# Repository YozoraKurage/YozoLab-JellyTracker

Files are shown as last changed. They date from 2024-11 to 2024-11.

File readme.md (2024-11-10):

# Yozolab-JellyTracker

### ✨️現在作成中です！✨️

私の作った[SlimeVR](https://github.com/SlimeVR)トラッカーに関するリポジトリです。

## FW書き込みについて(書き途中です)
JellyTrackerを私から購入した場合、WebページからFWの更新ができます \
https://jt-webflash.yozolab.net/

## 動作確認済みデータ
- [x] JellyTracker_V0.2.0
- [x] JellyTracker_V0.5.0
- [x] LSM_Module_V0.1.0
- [x] Ni-MH_3.3V-Module_V0.1.0

## KiCADデータについて
(今のところ)すべてKiCAD 7.0で作成されています\
私の導入しているプラグイン
- Espressif Library
- KiCAD JLCPCB tools

## JT_V0.5.0
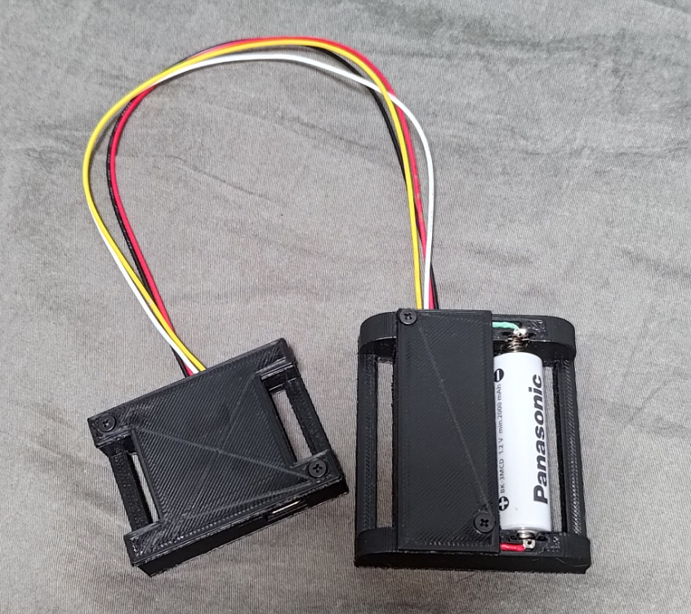
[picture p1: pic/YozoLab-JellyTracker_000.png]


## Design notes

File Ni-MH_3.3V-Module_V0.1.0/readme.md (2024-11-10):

# NiMH 3.3V昇圧モジュール
Ni-MHを3.3Vへ昇圧するモジュールです。

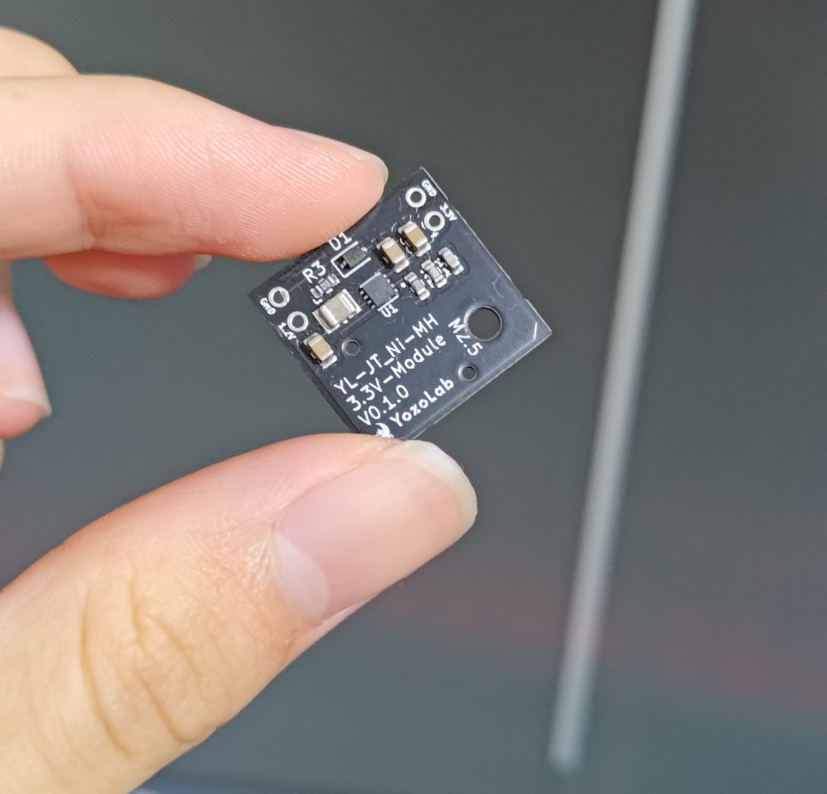
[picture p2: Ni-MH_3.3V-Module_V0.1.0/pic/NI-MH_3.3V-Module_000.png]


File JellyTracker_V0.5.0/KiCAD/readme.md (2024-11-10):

# JellyTracker_V0.5.0 KiCADデータ

> [!NOTE]
> このKiCADデータはKiCAD V7.0で作成されました！

AUXトラッカーとして、LSM_Module-V0.1.0が利用可能です
> LSM_ModuleとNi-MH_3.3V-Moduleを利用してNi-MH一本での運用が可能です。\
> JT_V0.5.0はそのために作成されました

## How to Upload to JLCPCB
jlcpcb/production_filesに出力されたBOM、CPL、GERBERデータがあるので、それを使うかKiCADからデータを作成してください

## Parts list

| What's it? | Parts Name | LCSC No. |
| ---- | ---- | ---- |
| TypeC Connector | TYPE-C-31-M-12 | C165948 |
| ESP32C3 Module | ESP32-C3-WROOM-02-N4 | C2934560 |
| 3.3V Regulator | ME6211C33M5G-N | C82942 |
| PushButton | SKRKAEE020 | C115357 |
| Caps | CL21B105KBFNNNE | C28323 |
| Resistor | 0603WAF5101T5E  | C23186 |
| Resistor | 0603WAF1002T5E  | C25804 |
| Diode | CUS10S30,H3F | C146335 |
| PH 2.0 | PH-4P | C50137 |

> [!IMPORTANT]
> 私のPH2.0ケーブルでは、必ず **SameSide** のケーブルを使う必要があります！

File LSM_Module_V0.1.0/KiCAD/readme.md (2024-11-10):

# LSM_Module_V0.1.0 KiCADデータ

LSM6シリーズ、及びBMIシリーズのモジュールにコネクタを付けてAUXトラッカーとして扱うための基板データです。

白猫屋さんのこのLSM6DSVモジュールでの動作を確認済みです。\
https://booth.pm/ja/items/5606882

## How to Upload to JLCPCB
jlcpcb/production_filesに出力されたBOM、CPL、GERBERデータがあるので、それを使うかKiCADからデータを作成してください

## Parts list
| Parts Name | LCSC No. |
| ---- | ---- |
| PH2.0mm 4pin | C50137 or https://www.aliexpress.com/item/1005006027334406.html |
| PH2.0mm 4pin-wire **SameSide** | https://ja.aliexpress.com/item/1005003395992629.html |

> [!IMPORTANT]
> 私のPH2.0ケーブルでは、必ず **SameSide** のケーブルを使う必要があります！

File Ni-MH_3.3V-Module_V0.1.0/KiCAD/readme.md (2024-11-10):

# NiMH 3.3V昇圧モジュール KiCADデータ
Ni-MHを3.3Vへ昇圧するモジュールです。

## How to Upload to JLCPCB
jlcpcb/production_filesに出力されたBOM、CPL、GERBERデータがあるので、それを使うかKiCADからデータを作成してください

## Parts list
| What's it? | Parts Name | LCSC No. |
| ---- | ---- | ---- |
| Caps | CL10C100JB8NNNC | C1634 |
| Inductor | DFE252012P-R47M=P2 | C237552 |
| Resistor | 0603WAF3163T5E | C25814 |
| 1.2v to 3.3v DCDC | TPS61021ADSGR | C193037 |
| Caps | CL21A226MAQNNNE  | C45783 |
| Resistor | 0603WAF1003T5E | C25803 |
| Diode | CUS10S30,H3F | C146335 |

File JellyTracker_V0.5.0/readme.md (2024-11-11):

# JellyTracker_V0.5.0

JT_V0.5.0は動作確認済みです！

この基板では、ESP32-C3-WROOM-02-N4とLSM6DSVのモジュールを利用して作るトラッカーです。

白猫屋さんのこのLSM6DSVモジュールでの動作を確認済みです。\
https://booth.pm/ja/items/5606882

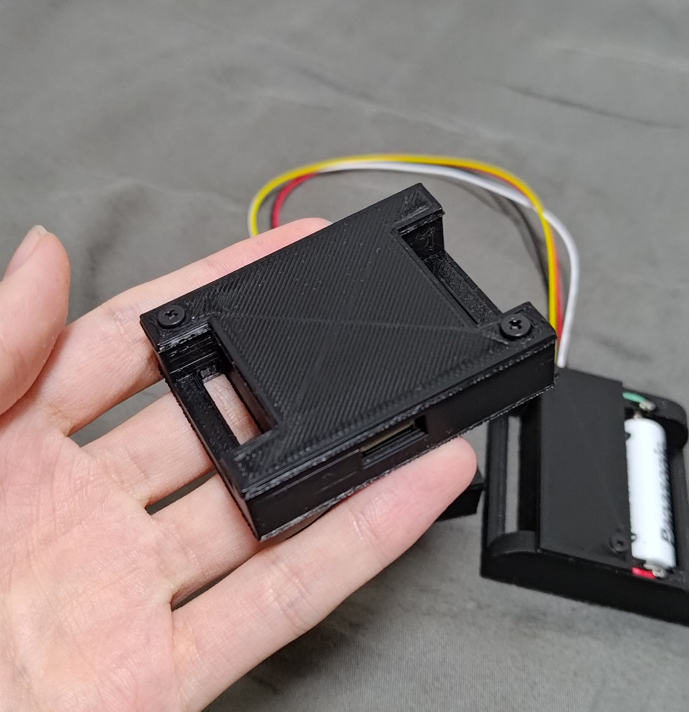
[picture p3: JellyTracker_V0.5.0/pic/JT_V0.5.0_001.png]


# JellyTracker_V0.5.0 FW

JT_V0.5.0で書き込み可能なカスタム済みFW一覧です。

> [!NOTE]
> FWデータは[JellyTracker-FW](https://github.com/YozoraKurage/JellyTracker-FW)リポジトリに移動しました！

| Branch Name | Repository |  |
| ---- | ---- | ---- |
| sfusion-tuned-mbe_V0.5.0 | https://github.com/YozoraKurage/JellyTracker-FW/tree/sfusion-tuned-mbe_V0.5.0 | 安定版 |
| dynamic-sfusion_V0.5.0 | https://github.com/YozoraKurage/JellyTracker-FW/tree/dynamic-sfusion_V0.5.0 | 実験的 |

## How to Flash FW
JT-V0.5.0であれば、[YozoraLaboratory ESPTool](https://jt-webflash.yozolab.net/)からWeb上でのFW書き込みが可能です。\
カスタマイズしたい場合はそれぞれFWをダウンロードしてお使いください。

## Topics

JT-V0.5.0のFWはすべて、Ni-MH1本での運用に対応するために
- 電源投入時にDeepSleepへ入る処理(RFキャリブレーションのスキップ)
- WiFiの出力強度の変更(2dbm)
- CPUクロック数の変更(80MHz)

が行われています。\
これらは主に省電力化、電源投入時の突入電流対策です。

また、sfusion-tuned-mbeではCPUクロックが80MHzで耐えられなかったため、180Mhzへと変更されています。

## 各FWについて

### sfusion-tuned-mbe_V0.5.0では
FWを書き込んだ初回にのみ6面キャリブレーションが必要です。\
詳しくは[公式ドキュメント](https://docs.slimevr.dev/server/imu-calibration.html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)を御覧ください。\
(このFWは起動時にDeepSleepへと突入するため、シリアルコンソールが一時的に外され、6面キャリブレーションが少しやりにくくなっています！ごめんなさい;;)

### dynamic-sfusion_V0.5.0では
これは6面キャリブレーションが必要ないFWです。\
現在実験中！\
~~例として、[PandaTrackers](https://github.com/purraricat/SlimeVR-CheeseCake-PandaTrackers/blob/main/docs/LSM6DSV-tips.md)ではMBEは非推奨と書かれています。(2024/11/10時点)~~\
彼はSlimeVR Discordコミュニティから正当な理由によってBANされているようでした...

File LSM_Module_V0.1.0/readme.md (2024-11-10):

# LSM_Module_V0.1.0
LSM6シリーズ、及びBMIシリーズのモジュールにコネクタを付けてAUXトラッカーとして扱うための基板データです。

白猫屋さんのこのLSM6DSVモジュールでの動作を確認済みです。\
https://booth.pm/ja/items/5606882

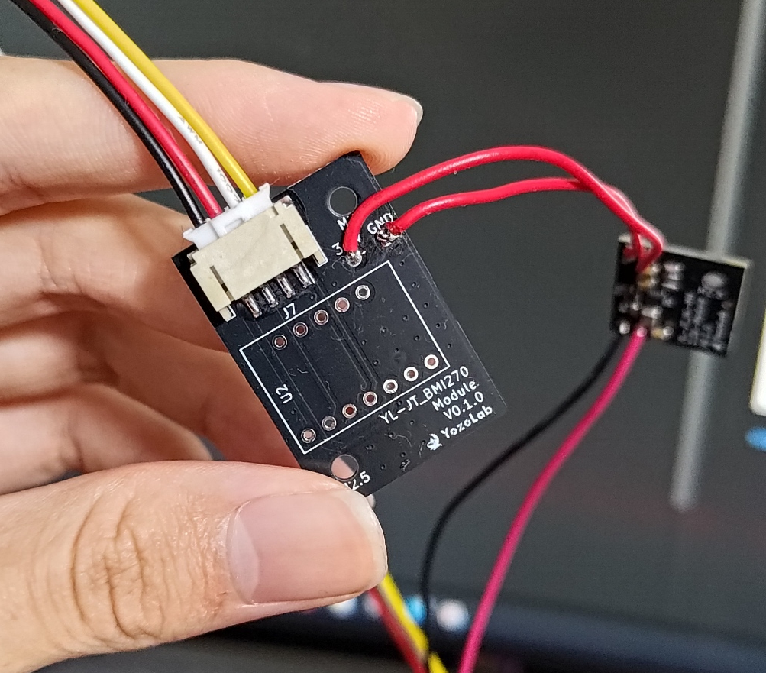
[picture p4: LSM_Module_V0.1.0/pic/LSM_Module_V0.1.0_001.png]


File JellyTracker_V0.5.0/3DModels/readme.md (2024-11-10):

# JellyTracker_V0.5.0 3DModels
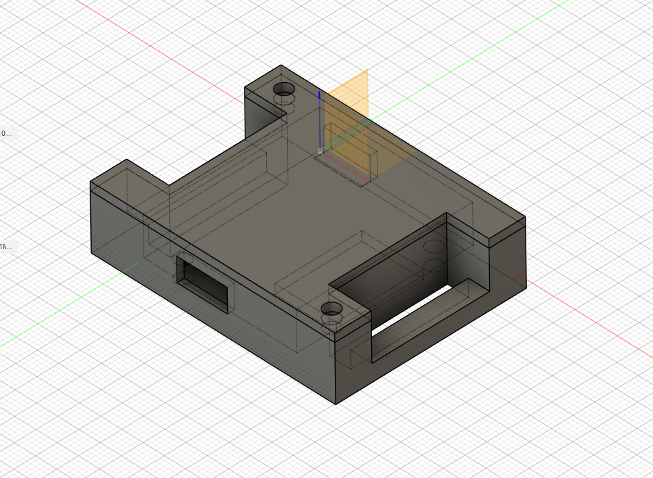
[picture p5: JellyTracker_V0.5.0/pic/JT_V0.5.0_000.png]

ネジは2.5M、穴が空いているところに2.5M、幅3.5mmインサートナットをねじ込む感じです

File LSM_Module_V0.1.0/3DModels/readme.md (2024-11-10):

# JellyTracker_V0.5.0 3DModels
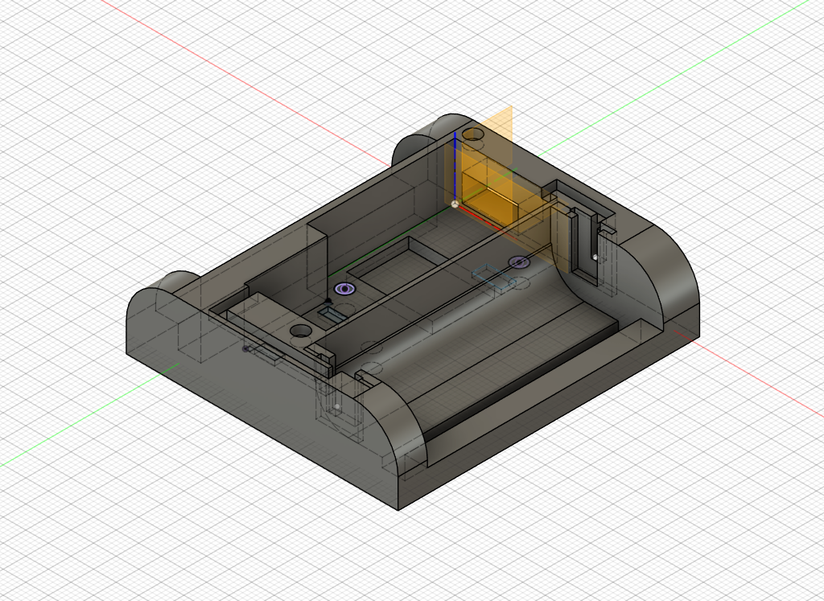
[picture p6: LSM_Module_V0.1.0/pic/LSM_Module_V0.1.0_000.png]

ネジは2.5M、穴が空いているところに2.5M、幅3.5mmインサートナットをねじ込む感じです

単3電池端子は[これ](https://www.amazon.co.jp/dp/B0C57XDT56?ref=ppx_yo2ov_dt_b_fed_asin_title&th=1)

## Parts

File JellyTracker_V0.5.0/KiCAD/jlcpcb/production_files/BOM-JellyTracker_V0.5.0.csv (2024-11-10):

Comment | Designator | Footprint | LCSC | Quantity
SW_Push | SW1,SW2 | SW_Push_SPST_NO_Alps_SKRK | C115357 | 2
CUS10S30 | D2 | D_SOD-323 | C146335 | 1
USB_C_Receptacle_USB2.0 | J1 | USB_C_Receptacle_HRO_TYPE-C-31-M-12 | C165948 | 1
5.1k | R1,R2 | R_0603_1608Metric | C23186 | 2
10k | R3,R4 | R_0603_1608Metric | C25804 | 2
1μF | C6,C7 | C_0805_2012Metric | C28323 | 2
ESP32-C3-WROOM-02 | U5 | ESP32-C3-WROOM-02 | C2934560 | 1
JST-PH 2.0 | J7 | JST_PH_S4B-PH-SM4-TB_1x04-1MP_P2.00mm_Horizontal | C50137 | 1
ME6211C33M5G-N | U1 | SOT-23-5 | C82942 | 1

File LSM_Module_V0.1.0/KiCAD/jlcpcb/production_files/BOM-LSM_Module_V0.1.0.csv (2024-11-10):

Comment | Designator | Footprint | LCSC | Quantity
JST-PH 2.0 | J7 | JST_PH_S4B-PH-SM4-TB_1x04-1MP_P2.00mm_Horizontal | C50137 | 1

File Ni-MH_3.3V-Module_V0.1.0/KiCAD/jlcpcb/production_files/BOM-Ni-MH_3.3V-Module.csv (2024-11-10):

Comment | Designator | Footprint | LCSC | Quantity
CUS10S30 | D1 | D_SOD-323 | C146335 | 1
10pF | C2 | C_0603_1608Metric | C1634 | 1
TPS61021ADSGR | U1 | SON50P200X200X80-9N | C193037 | 1
DFE252012P-R47M=P2 | L1 | INDC2520X120N | C237552 | 1
100k | R2,R3 | R_0603_1608Metric | C25803 | 2
316k | R1 | R_0603_1608Metric | C25814 | 1
22uF | C1,C3,C4 | C_0805_2012Metric | C45783 | 3

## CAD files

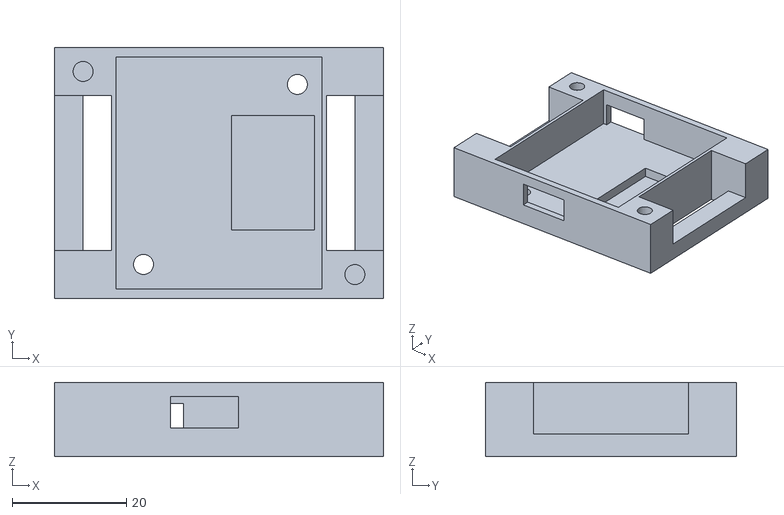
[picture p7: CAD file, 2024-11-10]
JellyTracker_V0.5.0/3DModels/JT-V0.5.0_Bottom.stl
57.6 x 43.9 x 13.0

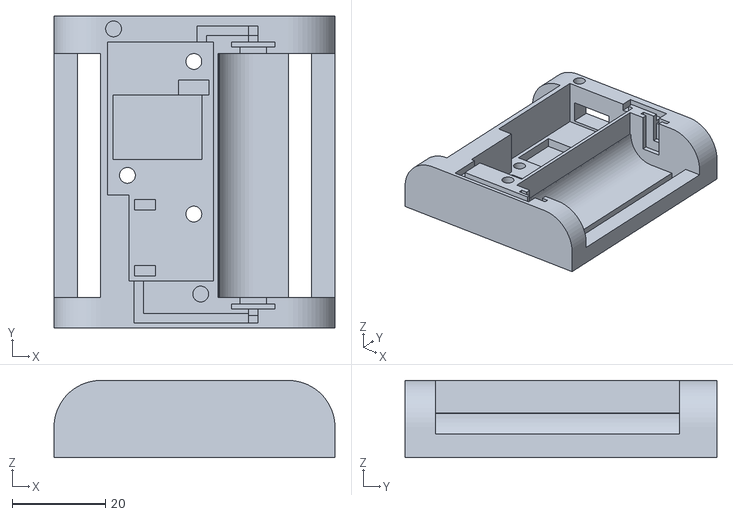
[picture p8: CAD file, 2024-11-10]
LSM_Module_V0.1.0/3DModels/LSMModule_V0.1.0_Bottom.stl
60.2 x 66.7 x 16.5

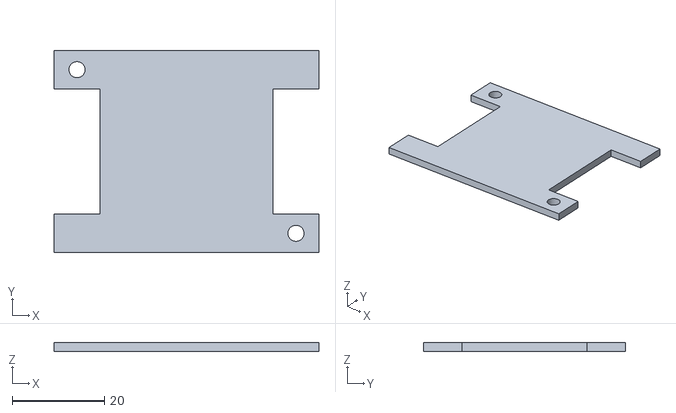
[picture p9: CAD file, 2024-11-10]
JellyTracker_V0.5.0/3DModels/JT-V0.5.0_Top.stl
57.6 x 43.9 x 2.00

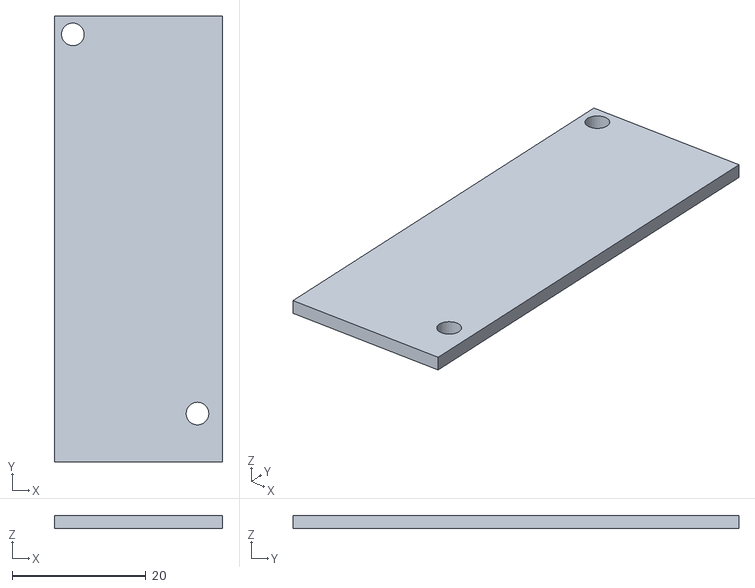
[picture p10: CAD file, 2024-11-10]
LSM_Module_V0.1.0/3DModels/LSMModule_V0.1.0-Top.stl
25.2 x 66.7 x 2.00

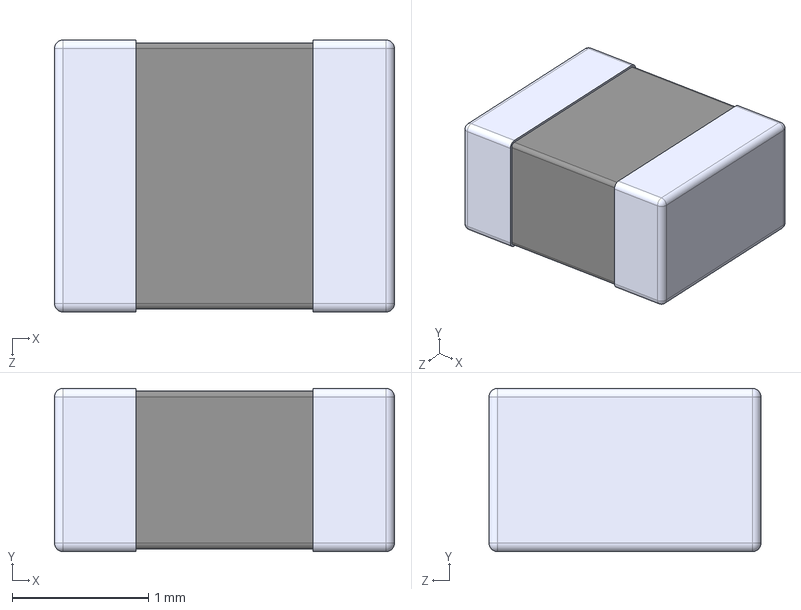
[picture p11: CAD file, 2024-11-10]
JellyTracker_V0.5.0/KiCAD/other.footprints/DFE252012P-R47M_P2/DFE252012P-R47M_P2.step
2.50 x 1.20 x 2.00 mm

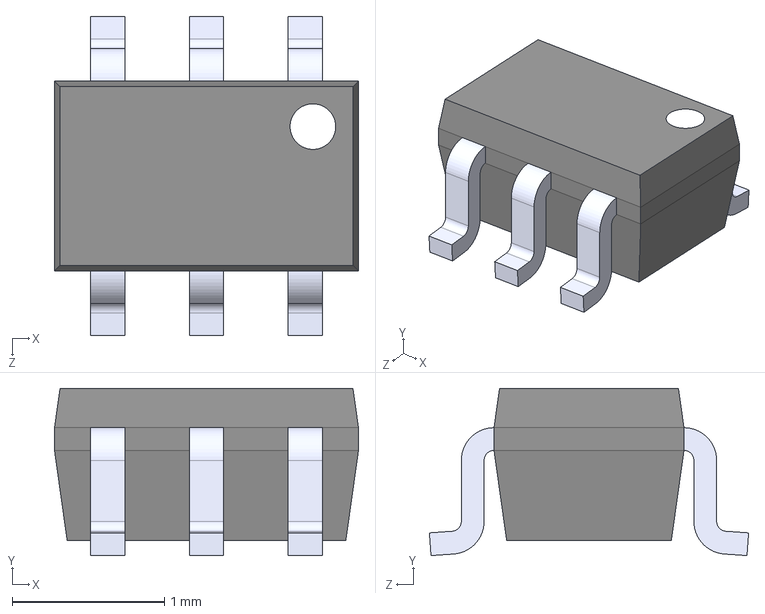
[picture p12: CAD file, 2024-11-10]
JellyTracker_V0.5.0/KiCAD/other.footprints/LM66100DCKR/LM66100DCKR.step
2.00 x 1.10 x 2.10 mm

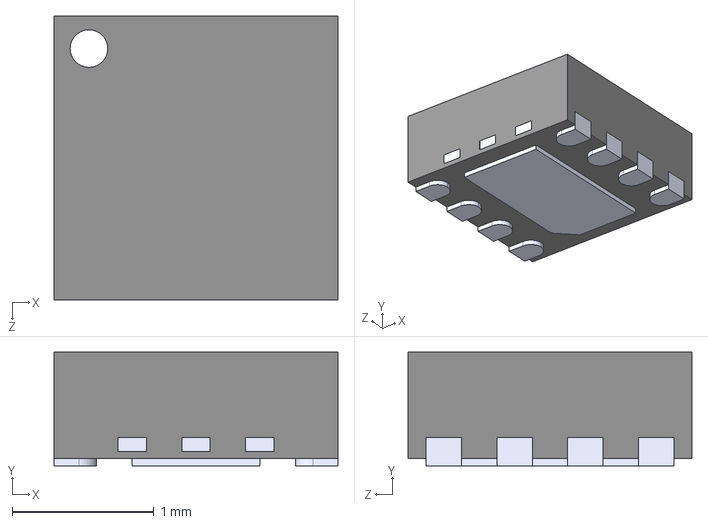
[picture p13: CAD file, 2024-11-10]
JellyTracker_V0.5.0/KiCAD/other.footprints/TPS61021ADSGR/TPS61021ADSGR.step
2.00 x 0.8 x 2.00 mm

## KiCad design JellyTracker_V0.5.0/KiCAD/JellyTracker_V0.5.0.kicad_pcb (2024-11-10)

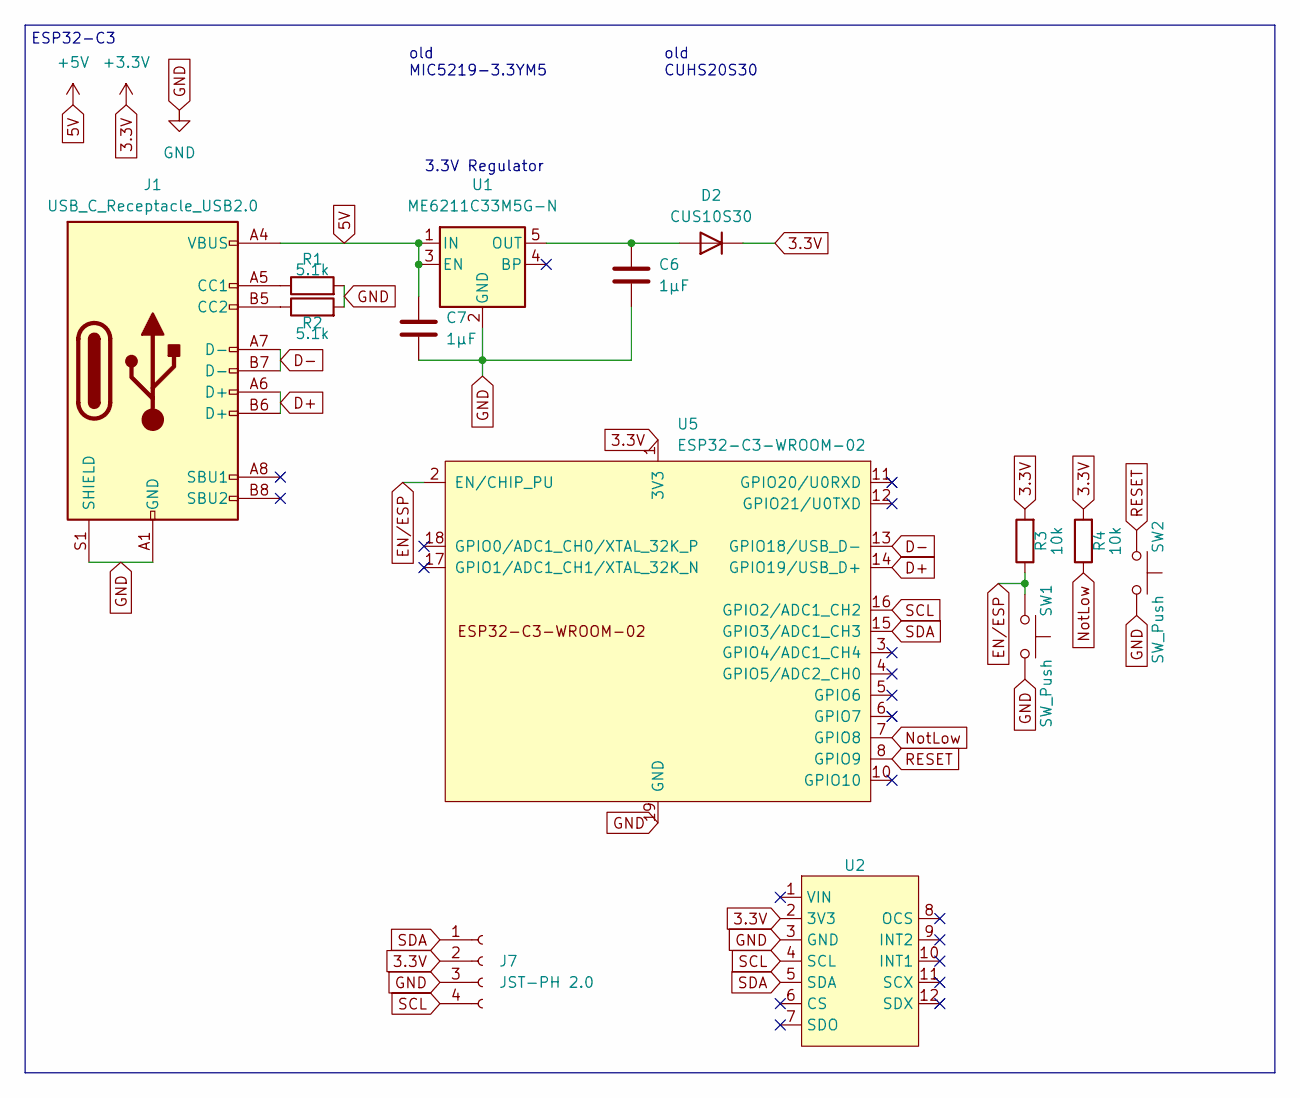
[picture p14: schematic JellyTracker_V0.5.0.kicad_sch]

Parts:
C6, C7: 1μF; C_0805_2012Metric
D2: CUS10S30; D_SOD-323
J1: USB_C_Receptacle_USB2.0; USB_C_Receptacle_HRO_TYPE-C-31-M-12
J7: JST-PH 2.0; JST_PH_S4B-PH-SM4-TB_1x04-1MP_P2.00mm_Horizontal
R1, R2: 5.1k; R_0603_1608Metric
R3, R4: 10k; R_0603_1608Metric
SW1, SW2: SW_Push; SW_Push_SPST_NO_Alps_SKRK
U1: ME6211C33M5G-N; SOT-23-5
U2: BMI160-Module
U5: ESP32-C3-WROOM-02

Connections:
3.3V: D2.1 (K), J7.2, R3.2, R4.2, U2.2 (3V3), U5.1 (3V3)
5V: C7.2, J1.A4 (VBUS), J1.A9 (VBUS), J1.B4 (VBUS), J1.B9 (VBUS), U1.1 (IN), U1.3 (EN)
D+: J1.A6 (D+), J1.B6 (D+), U5.14 (GPIO19/USB_D+)
D-: J1.A7 (D-), J1.B7 (D-), U5.13 (GPIO18/USB_D-)
EN/ESP: R3.1, SW1.1, U5.2 (EN/CHIP_PU)
GND: C6.2, C7.1, J1.A1 (GND), J1.A12 (GND), J1.B1 (GND), J1.B12 (GND), J1.S1 (SHIELD), J7.3, R1.2, R2.2, SW1.2, SW2.2, U1.2 (GND), U2.3 (GND), U5.9 (GND), U5.19 (GND)
unnamed: C6.1, D2.2 (A), U1.5 (OUT)
unnamed: J1.A5 (CC1), R1.1
unnamed: J1.B5 (CC2), R2.1
NotLow: R4.1, U5.7 (GPIO8)
RESET: SW2.1, U5.8 (GPIO9)
SCL: J7.4, U2.4 (SCL), U5.16 (GPIO2/ADC1_CH2)
SDA: J7.1, U2.5 (SDA), U5.15 (GPIO3/ADC1_CH3)

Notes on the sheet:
ESP32-C3
old CUHS20S30
3.3V Regulator
old MIC5219-3.3YM5

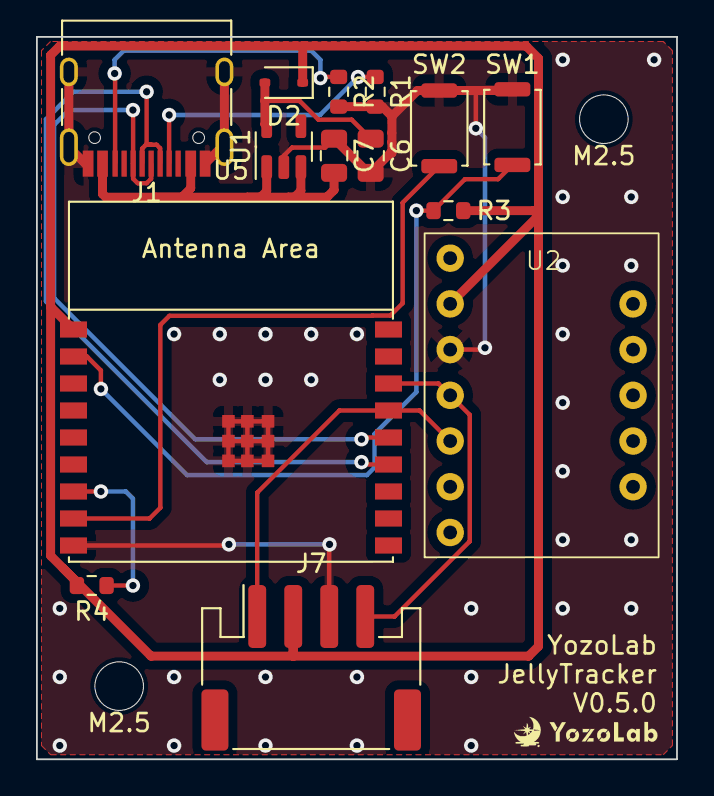
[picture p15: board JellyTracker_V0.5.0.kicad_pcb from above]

Board: 2 copper layers, 35.6 x 40.1 mm, 16 parts (0 on the bottom side), 13 nets.

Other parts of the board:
M2.5, M2.5#2: MountingHole_2.7mm_M2.5

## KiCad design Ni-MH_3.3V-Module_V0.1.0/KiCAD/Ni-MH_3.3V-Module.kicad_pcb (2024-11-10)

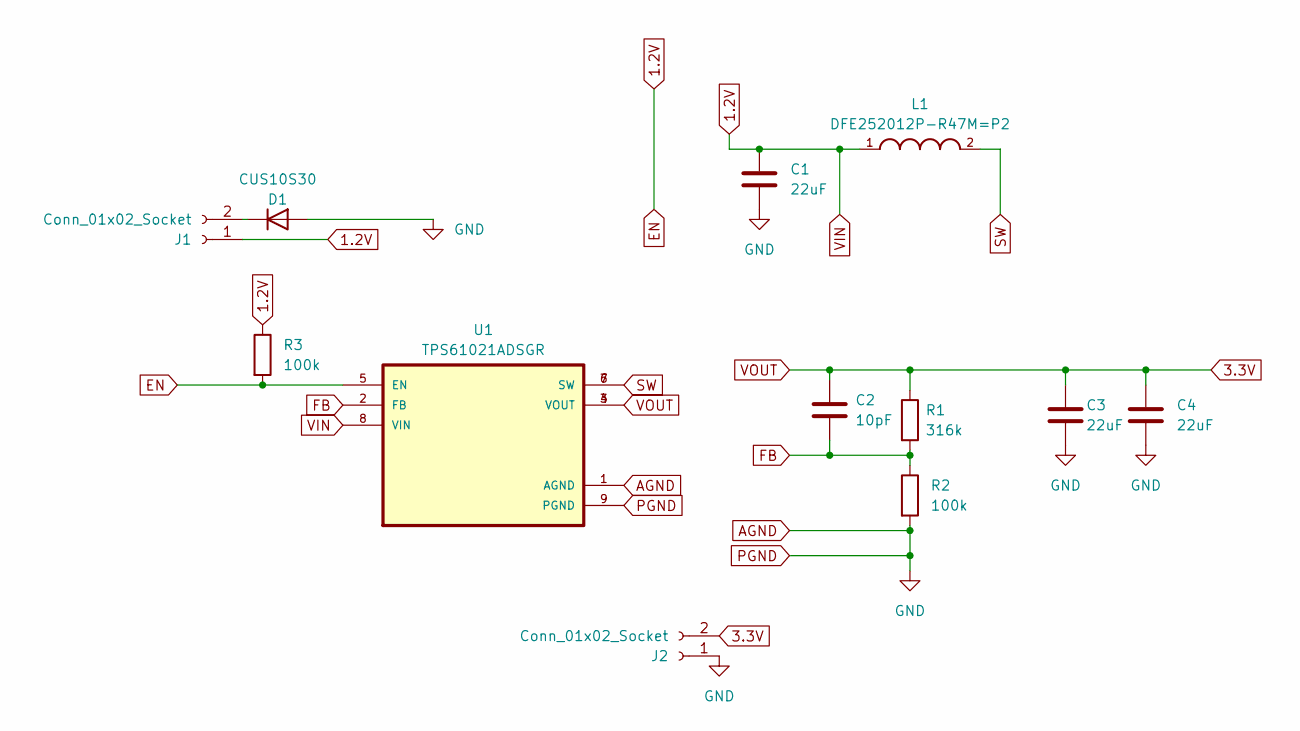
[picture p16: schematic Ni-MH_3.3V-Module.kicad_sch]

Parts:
C1, C3, C4: 22uF; C_0805_2012Metric
C2: 10pF; C_0603_1608Metric
D1: CUS10S30; D_SOD-323
J1, J2: Conn_01x02_Socket; Through-Hole
L1: DFE252012P-R47M=P2; INDC2520X120N
R1: 316k; R_0603_1608Metric
R2, R3: 100k; R_0603_1608Metric
U1: TPS61021ADSGR; SON50P200X200X80-9N

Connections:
1.2V: C1.2, J1.1, L1.1, R3.1, R3.2, U1.5 (EN), U1.8 (VIN)
3.3V: C2.2, C3.2, C4.2, J2.2, R1.1, U1.3 (VOUT), U1.4 (VOUT)
AGND: C1.1, C3.1, C4.1, D1.2 (A), J2.1, R2.2, U1.1 (AGND), U1.9 (PGND)
FB: C2.1, R1.2, R2.1, U1.2 (FB)
unnamed: D1.1 (K), J1.2
SW: L1.2, U1.6 (SW), U1.7 (SW)

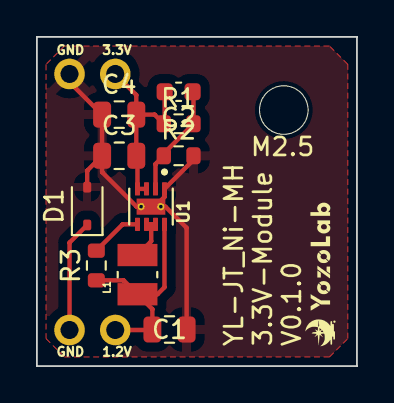
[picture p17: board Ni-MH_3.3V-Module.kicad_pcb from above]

Board: 2 copper layers, 17.8 x 18.3 mm, 13 parts (0 on the bottom side), 6 nets.

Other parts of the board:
M2.5: MountingHole_2.7mm_M2.5

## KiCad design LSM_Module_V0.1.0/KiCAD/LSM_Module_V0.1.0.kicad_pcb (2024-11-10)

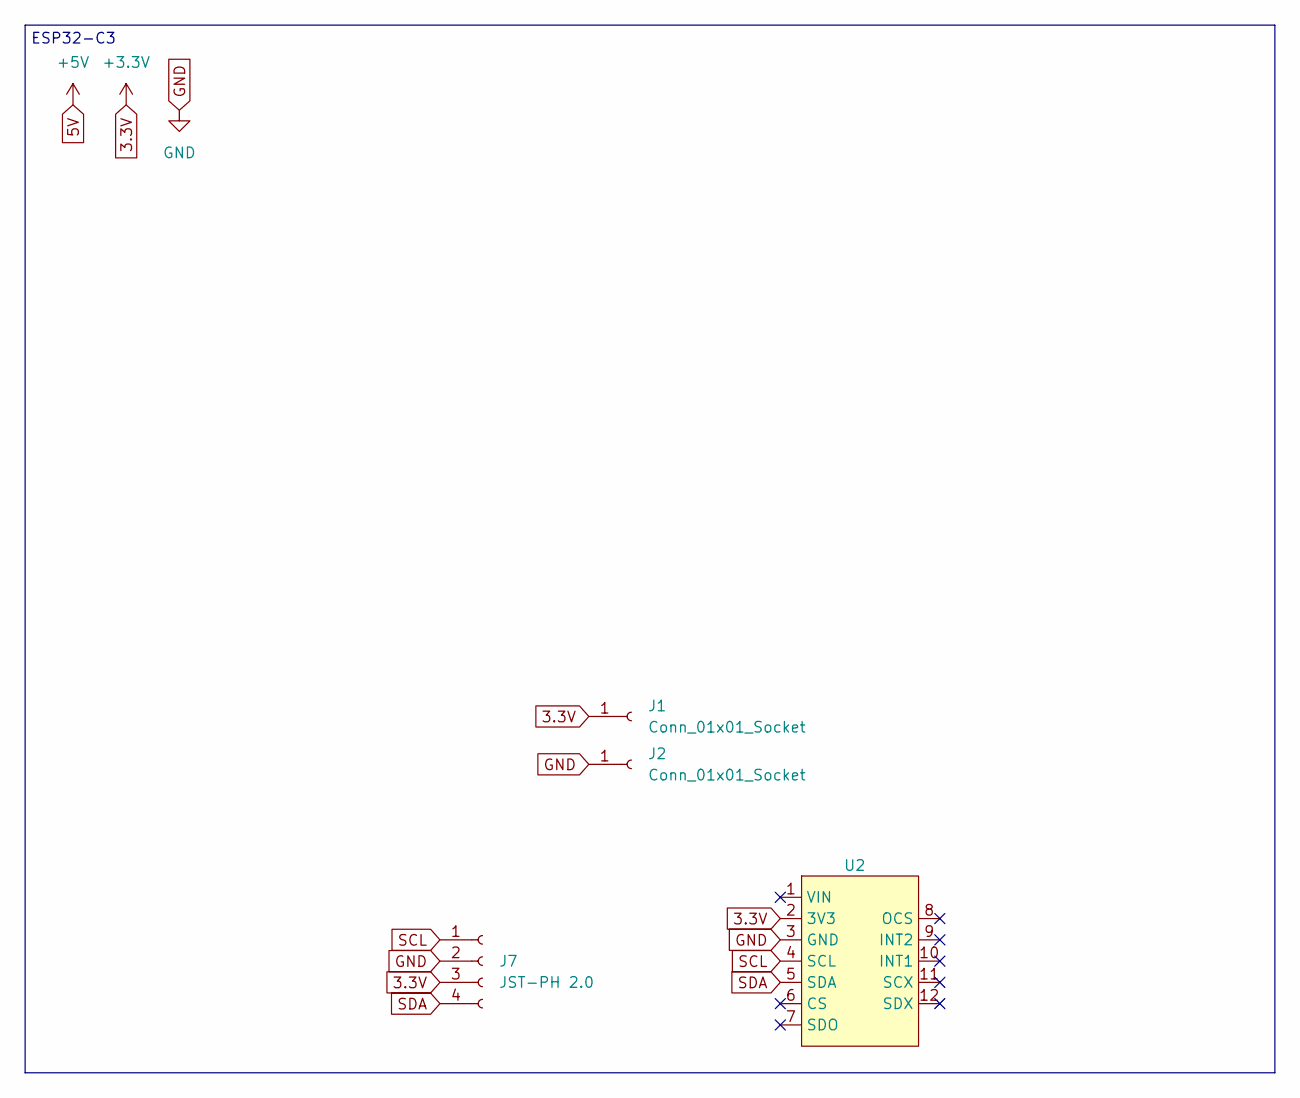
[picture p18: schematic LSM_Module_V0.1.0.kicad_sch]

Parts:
J1, J2: Conn_01x01_Socket; Through-Hole
J7: JST-PH 2.0; JST_PH_S4B-PH-SM4-TB_1x04-1MP_P2.00mm_Horizontal
U2: BMI160-Module

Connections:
3.3V: J1.1, J7.3, U2.2 (3V3)
GND: J2.1, J7.2, U2.3 (GND)
SCL: J7.1, U2.4 (SCL)
SDA: J7.4, U2.5 (SDA)

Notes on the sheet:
ESP32-C3

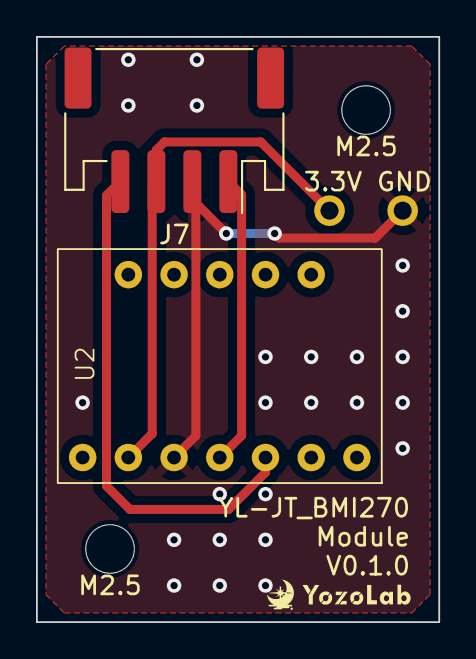
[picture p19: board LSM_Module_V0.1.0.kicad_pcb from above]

Board: 2 copper layers, 22.4 x 32.5 mm, 6 parts (0 on the bottom side), 4 nets.

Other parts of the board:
M2.5, M2.5#2: MountingHole_2.7mm_M2.5
